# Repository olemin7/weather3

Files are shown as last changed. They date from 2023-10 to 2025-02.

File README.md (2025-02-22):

# platformio
source ~/.platformio/penv/bin/activate
pio run
pio project init --ide eclipse
# clock
clock with ntp synk
# Board
http://arduino.esp8266.com/stable/package_esp8266com_index.json
# lib 
https://github.com/olemin7/esp_libs

# referenses
schematic: https://circuits.io/circuits/3798057-net-clock-led
gtest
https://www.codeproject.com/Articles/811934/Cplusplus-unit-test-start-guide-how-to-set-up-Goog
https://github.com/google/googletest.git
arduino:
https://github.com/arduino/Arduino/blob/master/build/shared/manpage.adoc

# esp8266 reference
http://www.kloppenborg.net/blog/microcontrollers/2016/08/02/getting-started-with-the-esp8266

##wemos
Pin | Function    | ESP-8266 Pin | used
TX  | TXD         | TXD          |
RX  | RXD         | RXD          |
A0  | ADC, 3.3V   | A0           | battery
D0  | IO          | GPIO16       |
D1  | IO, SCL     | GPIO5        | 
D2  | IO, SDA     | GPIO4        | 
D3  | IO, 10k P-up| GPIO0        | 
D4  | IO, 10k P-up,LED|   GPIO2  | DHT.data
D5  | IO, SCK     | GPIO14       | 
D6  | IO, MISO    | GPIO12       | 
D7  | IO, MOSI    | GPIO13       | 
D8  | IO, 10k P-down, SS|  GPIO15|
G   | Ground      | GND          |
5V  | 5V          | -            |
3V3 | 3.3V        | 3.3V         |
RST | Reset       | RST          |

#ADC wemos
 A0--
    |
   220K
    |--- ADC
   100K
    |
   GND
 
#battery
 vbat 130k --A0
 adc val= 848,volt=3.72656 (3.95

#DHT
1 vcc (3.3V)
2 data (D4)
3 nc
4 GND (G)

#deepsleep
D0->RST Connect GPIO16 to RST pin only after uploading the code

https://github.com/adam-p/markdown-here/wiki/Markdown-Cheatsheet#lists
https://diyi0t.com/how-to-reduce-the-esp8266-power-consumption/
https://www.electronicshub.org/esp8266-deep-sleep-mode/

#usb not tetected ubuntu 22.04
https://stackoverflow.com/questions/70123431/why-would-ch341-uart-be-disconnected-from-ttyusb
sudo dmesg
...
 1553.747636] ch341 3-1.4:1.0: ch341-uart converter detected
[ 1553.748179] usb 3-1.4: ch341-uart converter now attached to ttyUSB0
[ 1554.300543] input: BRLTTY 6.4 Linux Screen Driver Keyboard as /devices/virtual/input/input38
[ 1554.302801] usb 3-1.4: usbfs: interface 0 claimed by ch341 while 'brltty' sets config #1
[ 1554.303356] ch341-uart ttyUSB0: ch341-uart converter now disconnected from ttyUSB0

sudo apt remove brltty

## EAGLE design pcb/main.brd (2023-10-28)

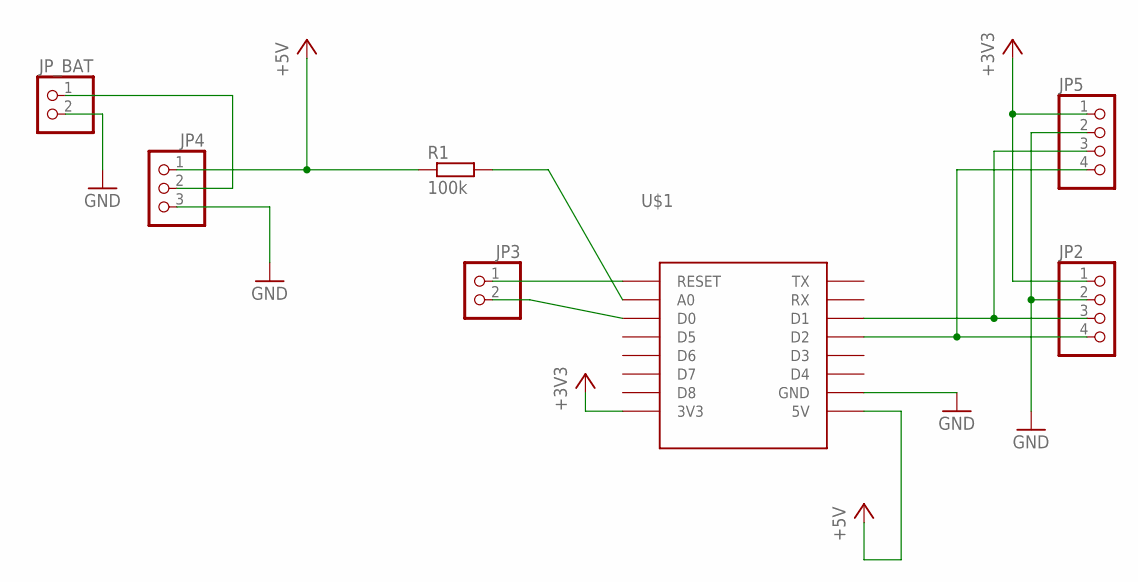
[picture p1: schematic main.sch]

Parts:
JP2, JP5: PINHD-1X4; 1X04
JP3: PINHD-1X2; 1X02
JP4: PINHD-1X3; 1X03
JP_BAT: PINHD-1X2; 1X02
R1: 100k; R0805
U$1: WEMOS-D1-MINI

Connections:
+3V3: JP2.1, JP5.1, U$1.3V3
+5V: JP4.1, R1.1, U$1.5V
GND: JP2.2, JP4.3, JP5.2, JP_BAT.2, U$1.GND
unnamed: JP4.2, JP_BAT.1
unnamed: R1.2, U$1.A0
unnamed: JP3.2, U$1.D0
unnamed: JP3.1, U$1.RESET
unnamed: JP2.4, JP5.4, U$1.D2
unnamed: JP2.3, JP5.3, U$1.D1

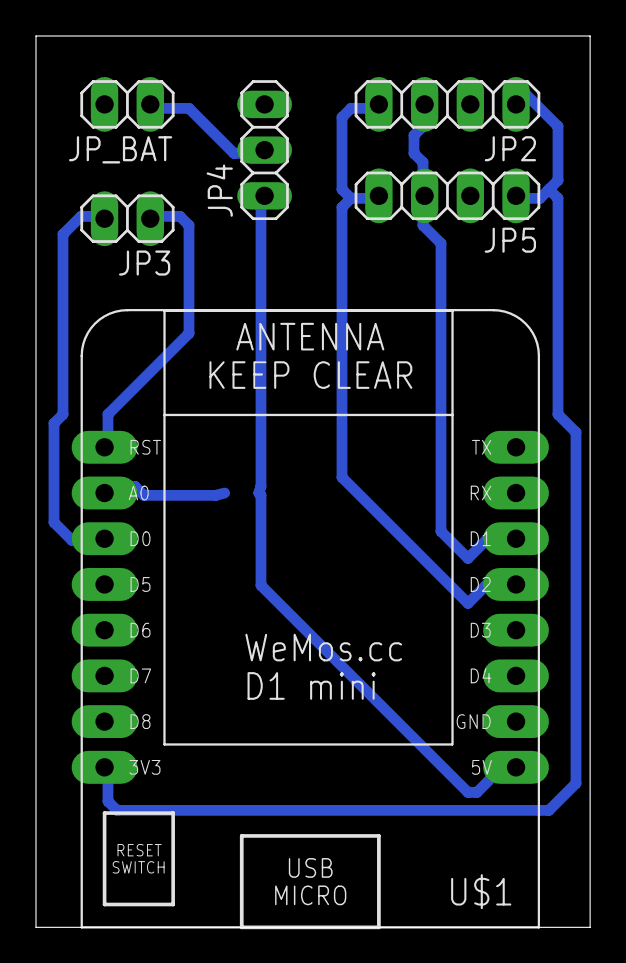
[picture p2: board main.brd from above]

Board: 2 copper layers, 30.8 x 49.5 mm, 7 parts (1 on the bottom side), 9 nets.

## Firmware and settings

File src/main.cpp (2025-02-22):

// #define DEBUG
// clang-format off
#include <Arduino.h>
#include <SPI.h>
#include <ESP8266WiFi.h>
#include <ESP8266WebServer.h>
#include <ESP8266mDNS.h>
#include <ESP8266HTTPUpdateServer.h>
#include <LittleFS.h>

#include <Wire.h> // must be included here so that Arduino library object file references work
#include <pgmspace.h>
#include <stdio.h>
#include <iostream>
#include <sstream>
#include <string>
#include <map>
#include <chrono>
#include <algorithm>

#include <CMQTT.h>

// clang-format on
#include <CConfig.h>
#include <cledstatus.h>
#include <eventloop.h>
#include <logs.h>
#include <misk.h>
#include <wifiHandle.h>
#include <ArduinoJson.h>

#include "sensors.h"

using namespace std;
using namespace std::chrono_literals;

constexpr auto SERIAL_BAUND    = 115200;
constexpr auto SERVER_PORT_WEB = 80;

constexpr auto AP_MODE_TIMEOUT           = 30s; // switch to ap if no wifi
constexpr auto AUTO_REBOOT_AFTER_AP_MODE = 5min; // switch to ap if no wifi
constexpr auto BEFORE_SLEEP_TIMEOUT      = 1s; //

#define DEVICE_NAME "weather3"
const char*    update_path = "/firmware";
constexpr auto DEF_AP_PWD  = "12345678";
constexpr auto DEVICE_FW = DEVICE_NAME " " __DATE__
                                       " " __TIME__;

using led_status::cled_status;

const char* pDeviceName = nullptr;

bool           is_service_mode  = false;
constexpr auto SERVICE_MODE_PIN = D5;

ESP8266WebServer        serverWeb(SERVER_PORT_WEB);
CMQTT                   mqtt;
ESP8266HTTPUpdateServer otaUpdater;
auto                    config = CConfig<512>();
cled_status             status_led;

StaticJsonDocument<512> sensors;

void try_tosend_data(bool force);
std::string get_MAC()
{
    uint8_t mac[6];
    char macStr[15] = {0};
    wifi_get_macaddr(STATION_IF, mac);
    sprintf(macStr, "%02X%02X%02X%02X%02X%02X", mac[0], mac[1], mac[2], mac[3], mac[4], mac[5]);
    return macStr;
}

te_ret get_about(ostream& out) {
    out << "{";
    out << "\"firmware\":\"" << DEVICE_FW << "\"";
    out << ",\"deviceName\":\"" << pDeviceName << "\"";
    out << ",\"resetInfo\":" << system_get_rst_info()->reason;
    out << "}";
    return er_ok;
}

te_ret get_status(ostream& out) {
    out << "{";
    out << "\"mqtt\":" << mqtt.isConnected();
    out << "}";
    return er_ok;
}

void deep_sleep() {
    if (is_service_mode) {
        DBG_OUT << "iservice_mode, deepSleep is disabled" << std::endl;
        return;
    }
    sensor::power_off();
    auto sleeptime_s = config.getInt("DEEP_SLEEP_S");
    if (sensors.containsKey("upd_period")) {
        sleeptime_s = sensors["upd_period"];
    }

    DBG_OUT << "deepSleep, sleeptime=" << sleeptime_s << "s" << std::endl;
    delay(1000);
    ESP.deepSleep(sleeptime_s * 1000000); // microseconds
}

void setup_WebPages() {
    DBG_FUNK();
    otaUpdater.setup(&serverWeb, update_path, config.getCSTR("OTA_USERNAME"), config.getCSTR("OTA_PASSWORD"));

    serverWeb.on("/restart", []() {
        webRetResult(serverWeb, er_ok);
        delay(1000);
        ESP.restart();
    });

    serverWeb.on("/about", [] { wifiHandle_send_content_json(serverWeb, get_about); });

    serverWeb.on("/status", [] { wifiHandle_send_content_json(serverWeb, get_status); });

    serverWeb.on("/filesave", []() {
        DBG_FUNK();
        if (!serverWeb.hasArg("path") || !serverWeb.hasArg("payload")) {
            webRetResult(serverWeb, er_no_parameters);
            return;
        }
        const auto path = string("/www/") + serverWeb.arg("path").c_str();
        cout << path << endl;
        auto file = LittleFS.open(path.c_str(), "w");
        if (!file) {
            webRetResult(serverWeb, er_createFile);
            return;
        }
        if (!file.print(serverWeb.arg("payload"))) {
            webRetResult(serverWeb, er_FileIO);
            return;
        }
        file.close();
        webRetResult(serverWeb, er_ok);
    });

    serverWeb.on("/scanwifi", HTTP_ANY, [&]() { wifiHandle_sendlist(serverWeb); });
    serverWeb.on("/connectwifi", HTTP_ANY, [&]() { wifiHandle_connect(pDeviceName, serverWeb, true); });

    serverWeb.on("/getlogs", HTTP_ANY, [&]() {
        serverWeb.send(200, "text/plain", log_buffer.c_str());
        log_buffer = "";
    });

    serverWeb.serveStatic("/", LittleFS, "/www/");

    serverWeb.onNotFound([] {
        Serial.println("Error no handler");
        Serial.println(serverWeb.uri());
        webRetResult(serverWeb, er_fileNotFound);
    });
    serverWeb.begin();
}

void setup_WIFIConnect() {
    DBG_FUNK();
    static event_loop::pevent to_ap_mode_thread;
    WiFi.hostname(pDeviceName);
    WiFi.begin();
    if (is_service_mode) {
        to_ap_mode_thread = event_loop::set_timeout(
            []() {
                DBG_OUT << "Rebooting" << std::endl;
                setup_wifi("", DEF_AP_PWD, pDeviceName, WIFI_AP, false);

                event_loop::set_timeout(
                    []() {
                        DBG_OUT << "Rebooting" << std::endl;
                        ESP.restart();
                    },
                    AUTO_REBOOT_AFTER_AP_MODE);
            },
            AP_MODE_TIMEOUT);
    }

    static WiFiEventHandler onStationModeConnected = WiFi.onStationModeConnected([](auto event) {
        DBG_OUT << "WiFi conected, ssid =" << event.ssid << ", channel=" << static_cast<unsigned>(event.channel)
                << endl;
    });

    static WiFiEventHandler onStationModeGotIP = WiFi.onStationModeGotIP([](auto event) {
        if (to_ap_mode_thread) {
            to_ap_mode_thread->cancel();
        }
        DBG_OUT << "WiFi IP=" << event.ip << ", mask=" << event.mask << ", gw=" << event.gw << endl;
        sensors["rssi"] = WiFi.RSSI();
        sensors["ip"] = event.ip.toString();

        event_loop::set_timeout(
            []() {
                DBG_OUT << "mqtt connection" << endl;
                mqtt.setup(config.getCSTR("MQTT_SERVER_IP"), config.getInt("MQTT_PORT"), pDeviceName);
                mqtt.connect([](auto is_connected)
                             {
                        if (is_connected) {
                            std::stringstream info;
                            info << "{\"sw\":\"" << DEVICE_FW << "\",\"mac\":\"" << get_MAC() << "\"}";
                            mqtt.publish("advertisement", info.str());
                            try_tosend_data(false);
                        }
                        else
                        {
                            deep_sleep();
                        } });
            },
            0s);
    });
}

bool is_data_collected(const JsonDocument& data) {

    if (sensors.containsKey("temperature") == false)
    {
        return false;
    }
    if (sensors.containsKey("pressure") == false)
    {
        return false;
    }
    if (sensors.containsKey("humidity") == false)
    {
        return false;
    }
    if (sensors.containsKey("ambient_light") == false)
    {
        return false;
    }

    if (data.containsKey("battery") == false) {
        return false;
    }
    if (data.containsKey("wifi") == false) {
        return false;
    }

    return true;
}

void try_tosend_data(bool force) {
    if (force || is_data_collected(sensors)) {
        DBG_OUT << "sensors used sz=" << sensors.memoryUsage() << endl;

        if (mqtt.isConnected()) {
            String json_string;
            serializeJson(sensors, json_string);
            mqtt.publish("devices/" + get_MAC() + "/sensors", json_string.c_str());
            mqtt.get_client().flush(); // force to send
            status_led.set(cled_status::value_t::Work);
        } else {
            status_led.set(cled_status::value_t::Warning);
            DBG_OUT << "mqtt is not connected, state=" << mqtt.get_client().state() << endl;
        }
        event_loop::set_timeout([]() { deep_sleep(); }, BEFORE_SLEEP_TIMEOUT);
    }
}

void collect_data() {
    DBG_FUNK();
    sensors.clear();
    sensor::bme280_get([](auto temperature, auto pressure, auto humidity, auto is_successful) {
        if (is_successful) {
            sensors["pressure"] = pressure;
            sensors["temperature"] = temperature;
            sensors["humidity"] = humidity;
            try_tosend_data(false);
        }
    });

    // sensor::sth30_get([](auto temperature, auto humidity, auto is_successful) {
    //     if (is_successful) {
    //         sensors["weather"]["temperature"] = temperature;
    //         sensors["weather"]["humidity"]    = humidity;
    //         try_tosend_data(false);
    //     }
    // });

    sensor::bh1750_light_get([](auto lux)
                             {
        sensors["ambient_light"] = static_cast<int>(lux);
        try_tosend_data(false); });

    sensor::battery_get([](const float volt) {
        const auto min        = config.getFloat("V_BAT_MIN");
        const auto max        = config.getFloat("V_BAT_MAX");
        auto       percentage = static_cast<int>((volt - min) * 100 / (max - min));
        if (percentage < 0) {
            percentage = 0;
        }
        if (percentage > 100) {
            percentage = 100;
        }

        DBG_OUT << "battery adc=" << volt << ", pers=" << percentage << std::endl;

        sensors["battery"] = percentage;

        sensors["upd_period"]         = config.getInt("DEEP_SLEEP_S");
        const auto low_bat_percentage = config.getInt("LOW_BAT_PERCENAGE");
        if (percentage < low_bat_percentage) {
            DBG_OUT << "low bat=" << percentage << ", Threshold=" << low_bat_percentage << std::endl;
            sensors["upd_period"] = config.getInt("DEEP_SLEEP_LOW_BAT_S");
        }

        try_tosend_data(false);
    });

    event_loop::set_timeout(
        []() {
            DBG_OUT << "MAX_COLLECT_TIME passed, sending as is" << endl;
            try_tosend_data(true);
        },
        chrono::seconds(config.getInt("MAX_COLLECT_TIME_S")));
}

void setup_config() {
    config.getConfig().clear();
    config.getConfig()["DEVICE_NAME"]          = DEVICE_NAME;
    config.getConfig()["MQTT_SERVER_IP"]       = "";
    config.getConfig()["MQTT_PORT"]            = 0;
    config.getConfig()["MQTT_TOPIC_SENSORS"]   = "sensors";
    config.getConfig()["OTA_USERNAME"]         = "";
    config.getConfig()["OTA_PASSWORD"]         = "";
    config.getConfig()["DEEP_SLEEP_S"]         = 60 * 15;
    config.getConfig()["DEEP_SLEEP_LOW_BAT_S"] = 60 * 60;
    config.getConfig()["MAX_COLLECT_TIME_S"]   = 15;
    config.getConfig()["V_BAT_MIN"]            = 2.4;
    config.getConfig()["V_BAT_MAX"]            = 4.2;
    config.getConfig()["LOW_BAT_PERCENAGE"]    = 30;
    if (!config.load("/www/config/config.json")) {
        // write file
        config.write("/www/config/config.json");
    }
    pDeviceName = config.getCSTR("DEVICE_NAME");
}

void setup() {
    pinMode(SERVICE_MODE_PIN, INPUT_PULLUP);
    Serial.begin(SERIAL_BAUND);
    Wire.begin();
    logs_begin();
    DBG_FUNK();

    hw_info(DBG_OUT);
    LittleFS.begin();
    event_loop::init();
    status_led.setup();
    status_led.set(cled_status::value_t::Processing);
    setup_config();
    sensor::init();
    collect_data();

    MDNS.addService("http", "tcp", SERVER_PORT_WEB);
    MDNS.begin(pDeviceName);
    setup_WebPages();

    LittleFS_info(DBG_OUT);
    is_service_mode = !deboncedPin(SERVICE_MODE_PIN, 30);
    if (is_service_mode) {
        DBG_OUT << "in service mode" << endl;
        status_led.set(cled_status::value_t::On);
    }

    //-----------------
    setup_WIFIConnect();

    DBG_OUT << "Setup done" << endl;
}

void loop() {
    serverWeb.handleClient();
    event_loop::loop();
    mqtt.loop();
}
